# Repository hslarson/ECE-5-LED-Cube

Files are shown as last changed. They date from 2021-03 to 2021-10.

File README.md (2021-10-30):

Cube GIF (https://photos.app.goo.gl/J5VMb96Lni4Fbc2d9 "More Images")

<hr />

### Main Program:

- <b> loop </b>
  - Calls the nextLayer() member  function of the Multiplexer class on a preset interval
  - While we wait for the next layer to be drawn, the loop calls the subtasks() function to perform several smaller tasks required to draw the matrix
- <b>subtasks</b>
  - Each subtask referenced in this function is called once for every complete matrix that is sent to the cube. The function must be reset after every iteration
  - The first step (case 0) is calling the checkVolume() member function of the MSGEQ7 class, this decides whether the subtasks function draws a volume matrix or a spectrum matrix
  - Next, we collect the data required to construct the matrix. This is only required if we are drawing a spectrum matrix
  - Then, we construct the matrix itself. This is handled entirely by the respective classes
  - Lastly, we queue the matrix we just drew, meaning that it will be shown in the next iteration of the loop

### Multiplexer Class:

- <b>setMatrix</b>
  - Uses memcpy to either queue a new matrix or allow the queued matrix to be shown
- <b>nextLayer</b>
  - Handles the drawing of individual layers and the queuing of matrices
  - First, calls the constructData() function to format the data in a way that the registers will understand
  - Then, calls the sendData() function to send the data to the cube
- <b>constructData</b>
  - A helper function for nextLayer() that handles the mapping of output pins and the conversion of the resultant binary array to an integer array
- <b>sendToCube</b>
  - Uses the SPI bus to send the data from the constructData() function to the shift registers

### MSGEQ7 Class:

- <b>getSpectrum</b>
  - Reads data from the MSGEQ7 breakout board using analogRead()
- <b>normSpectrum</b>
  - Takes the array from the getSpectrum() function and converts from 7 channels to 36
- <b>makeSpectrumMatrix</b>
  - Maps each frequency band to a specific column of the cube
  - Applies a threshold to the raw reading to decide how many LED’s to light in each column and constructs a Boolean matrix based on this data
- <b>queueMatrix</b>
  - Calls the setMatrix() member of the Multiplexer class to queue the matrix that was built by the makeSpectrumMatrix() function

### VolumeControl Class:

- <b>checkVolume</b>
  - Uses a timer and the getVolume() function to decide whether or not to draw a volume matrix
- <b>getVolume</b>
  - Reads data from the volume potentiometer and normalizes the reading
  - Creates a running average of the normalized readings
- <b>makeVolumeMatrix</b>
  - Takes the current volume reading and creates a Boolean matrix that displays the volume as front-to-back bars that ascend each column then move from left to right to the next column
- <b>queueMatrix</b>
  - Takes the matrix that was constructed by the makeVolumeMatrix and queues it to be shown on the cube

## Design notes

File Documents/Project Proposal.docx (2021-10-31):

Project Title: LED Matrix Audio Visualizer

Group Members: Hunter Larson, Andy Liu, Kaitlyn Yau

1. Project Goal and Functionality

Our goal is to create an LED cube with the primary function of visualizing audio signals. This will be accomplished by sampling the audio signal from a 3.5mm jack (plugged into a phone or other audio player) a 7-band frequency analyzer and dividing the output into 16 frequency bands.

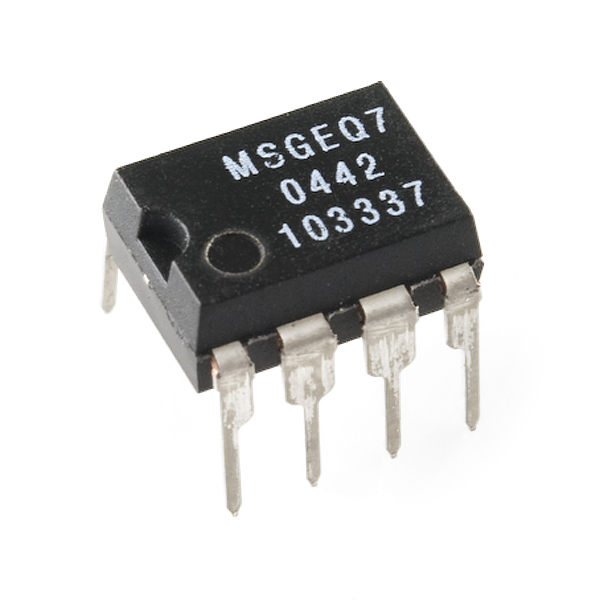
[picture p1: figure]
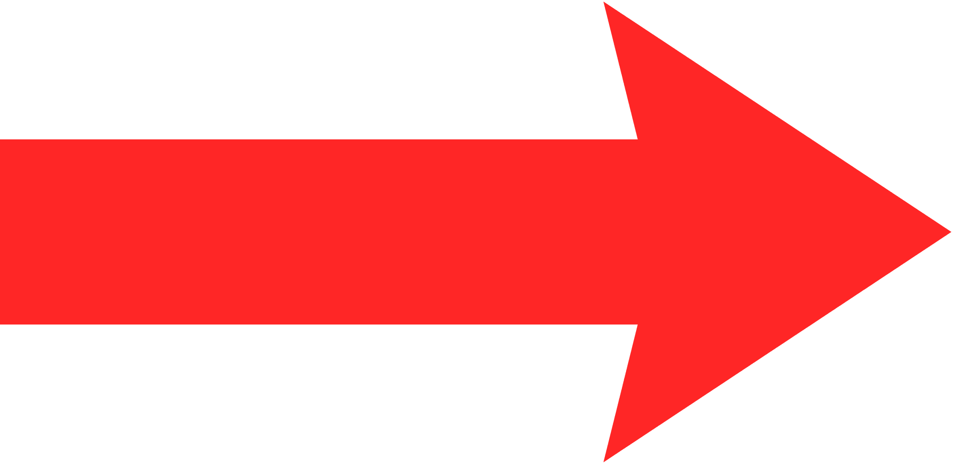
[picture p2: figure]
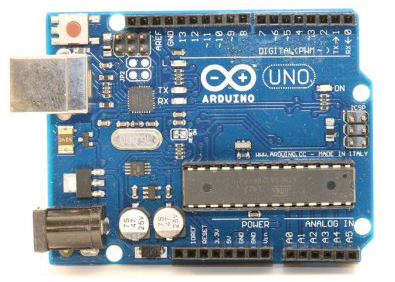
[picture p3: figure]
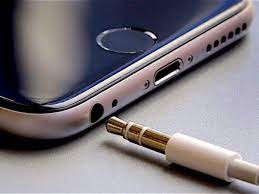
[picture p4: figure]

Figure 1: Process for decomposing audio into frequencies components (Image Credits (https://docs.google.com/document/d/1sJ7cVf4u0EIYqTToMvButSBCdlmTL1YI7-39VEIXNug/edit?usp=sharing))

Once we’ve computed the frequency bands, we will use shift registers to turn on certain columns in the matrix (each column in the cube shares a common anode) while powering only one layer at a time (each layer shares a common cathode). Repeating this process in rapid succession will allow us to create a persistence of vision effect, thus conveying the magnitude of each frequency band by varying the number of LED’s we turn on in each column.

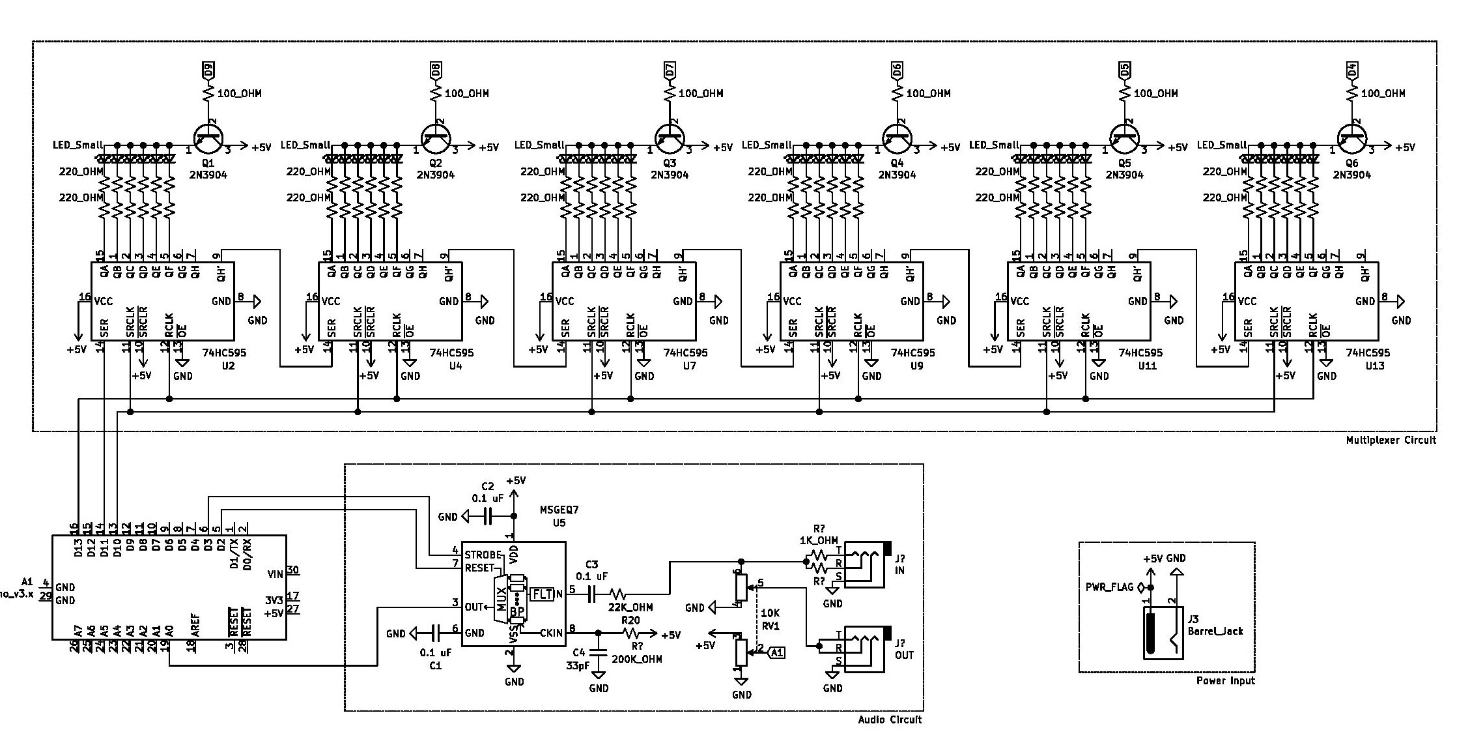
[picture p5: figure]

Figure 2: Shows the schematic for both the multiplexer and the MSGEQ7 circuit

Time permitting, we will add the ability to display other patterns on the cube when no audio source is connected.

2. Hardware Components
1. 1x Arduino Nano (Already Have)
2. 1x USB Wall Adapter & Cable w/ Barrel Jack (already have)
3. 1x (Female) Barrel Connector for Power (already have)
4. 1x Rocker Switch for Power (already have)
5. 2x 3.5mm Audio Jacks (already have)
6. 6x NPN Transistors (Already Have)
7. 1x Protoboard (https://www.amazon.com/Double-Sided-Protoboard-Prototyping-10X15CM/dp/B07HFFLGFV)
8. 1x Seven Band Spectrum Analyzer Board (https://www.amazon.com/MSGEQ7-Spectrum-Analyzer-Breakout-Stereo/dp/B08GY46BY8?s=electronics)
9. 216x D (https://www.amazon.com/100pcs-Ultra-Bright-Emitting-Diffused/dp/B01GE5NB5U)iffused, White LED’s (https://www.amazon.com/100pcs-Ultra-Bright-Emitting-Diffused/dp/B01GE5NB5U)
10. 72x 220-ohm Resistors (https://www.amazon.com/Projects-100EP512220R-220-Resistors-Pack/dp/B0185FID0K)
11. 6x Shift Registers (https://www.amazon.com/MCIGICM-74HC595-SN74HC595N-Register-registers/dp/B07HFWB9L9)
12. 6x IC Sockets (https://www.amazon.com/Uxcell-a11090300ux0244-2-54mm-Socket-Adaptors/dp/B0079SM1LW)
13. 3x Ribbon Cables (https://www.amazon.com/gp/product/B07FKRYJVR/ref=ppx_yo_dt_b_asin_title_o02_s00?ie=UTF8&psc=1)
14. 3x Connectors For Ribbon Cables (https://www.amazon.com/JZK-crimper-crimping-connectors-assorted/dp/B07PCQ5VMV)

Price Breakdown:

1. Arduino - $0
2. Power Supply - $0
3. Barrel Connector - $0
4. Rocker Switch - $0
5. 3.5mm Jacks - $0
6. Transistors - $0
7. Protoboard - $12
8. Spectrum Analyzer - $20
9. LED’s - $19
10. Resistors - $7
11. Shift Registers - $7.50
12. IC Sockets - $7
13. Ribbon Cables - $9
14. Ribbon Cable Connectors - $7

Total: $81.5

3. Design Timeline
1. Week 5: Order parts
2. Week 6: Start building LED Matrix, Start Controller Circuit
3. Week 7: Finish Controller Circuit, Start Programing
4. Week 8: Finish Programming, finish building LED matrix
5. Week 9: Debugging and/or Additional Patterns
4. Documentation
1. Github Repo (https://github.com/hslarson/ECE-5-LED-Cube)
2. MSGEQ7 Datasheet (https://www.digikey.com/htmldatasheets/production/1844111/0/0/1/msgeq7.html)
3. LED Datasheet (https://www.vishay.com/docs/85198/vlhw4100.pdf)
4. Shift Register Datasheet (https://www.ti.com/lit/ds/scls041i/scls041i.pdf?ts=1611948098373)
5. Transistor Datasheet (https://www.sparkfun.com/datasheets/Components/2N3904.pdf)

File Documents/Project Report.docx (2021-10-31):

LED Matrix Audio Visualizer

Group Members: Hunter Larson, Andy Liu, Kaitlyn Yau

# 1. Device Functionality

We created a 6x6x6 LED cube with the primary function of visualizing audio signals. This will be accomplished by sampling the audio signal from a 3.5mm jack (plugged into a phone or other audio player) with the MSGEQ7, a 7-band graphic equalizer and dividing the output into 36 frequency bands.

Once we’ve computed the frequency bands, we will use shift registers to turn on certain columns in the matrix (each column in the cube shares a common anode) while powering only one layer at a time (each layer shares a common cathode). Repeating this process in rapid succession will allow us to create a persistence of vision effect, thus conveying the magnitude of each frequency band by varying the number of LED’s we turn on in each column

# 2. Hardware Components

1. 1x Arduino Nano (already have)
2. 1x USB Wall Adapter & Cable w/ Barrel Jack (already have)
3. 1x (Female) Barrel Connector for Power (already have)
4. 1x Rocker Switch for Power (already have)
5. 2x 3.5mm Audio Jacks (already have)
6. 6x NPN Transistors (Already Have)
7. 1x Protoboard (https://www.amazon.com/Double-Sided-Protoboard-Prototyping-10X15CM/dp/B07HFFLGFV) ($12.00)
8. 1x Seven Band Spectrum Analyzer Board (https://www.amazon.com/MSGEQ7-Spectrum-Analyzer-Breakout-Stereo/dp/B08GY46BY8?s=electronics) ($20.00)
9. 216x Diffused, White LED’s (https://www.amazon.com/100pcs-Ultra-Bright-Emitting-Diffused/dp/B01GE5NB5U) ($19.00)
10. 72x 220-ohm Resistors (https://www.amazon.com/Projects-100EP512220R-220-Resistors-Pack/dp/B0185FID0K) ($7.00)
11. 6x Shift Registers (https://www.amazon.com/MCIGICM-74HC595-SN74HC595N-Register-registers/dp/B07HFWB9L9) ($7.50)
12. 6x IC Sockets (https://www.amazon.com/Uxcell-a11090300ux0244-2-54mm-Socket-Adaptors/dp/B0079SM1LW) ($8.00)
13. 3x Ribbon Cables (https://www.amazon.com/gp/product/B07FKRYJVR/ref=ppx_yo_dt_b_asin_title_o02_s00?ie=UTF8&psc=1) ($9.00)
14. 3x Connectors For Ribbon Cables (https://www.amazon.com/JZK-crimper-crimping-connectors-assorted/dp/B07PCQ5VMV)($7.00)

Total: $89.50

# 3. Design Timeline

Week 5: Found and ordered the parts needed for our project

Week 6: Began building the cube, managed to solder our 6 layers of LED’s.

Week 7: Came up with potential solutions to attaching our 6 layers of LED’s together (which we were having trouble with at the end of week 6). Began programming.

Week 8: Successfully attached the 6 layers of LED’s together to finish making our cube. Continued programming.

Week 9: Finished programming. Began and finished multiplexer circuit. Began audio circuit

Week 10: Finished audio circuit, attached cube to circuit. Currently debugging.

# 4. Software Design

https://github.com/hslarson/ECE-5-LED-Cube The README in the github link contains the details of every function we used including the ones in the flowchart below. There, you can also find our completed code.

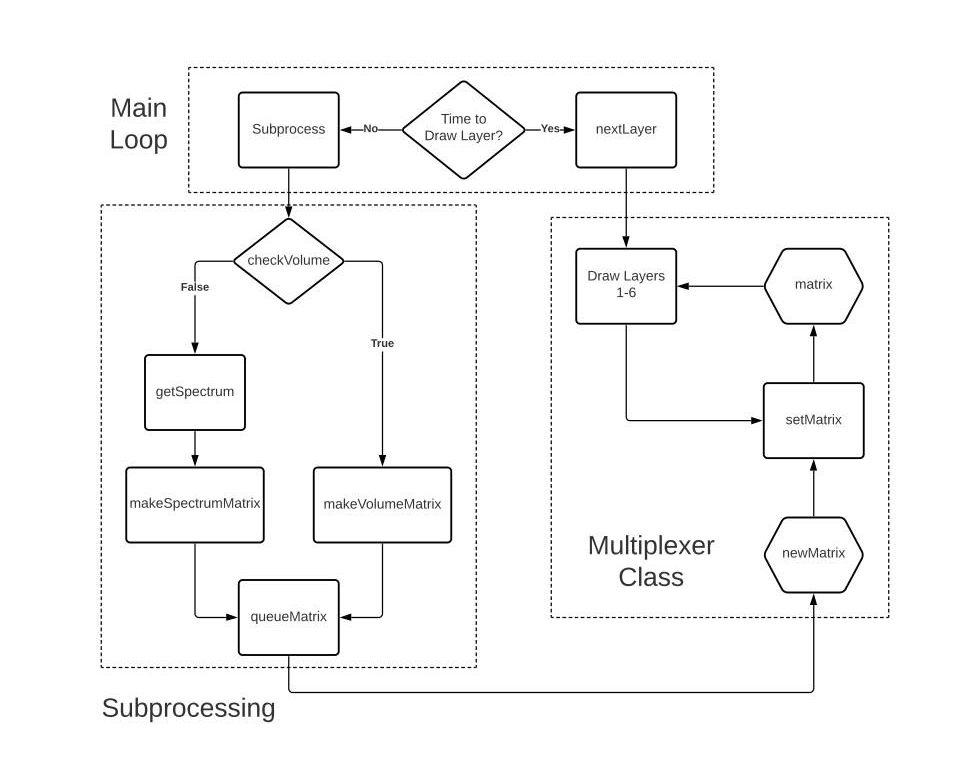
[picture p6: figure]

# 5. Circuit Schematic

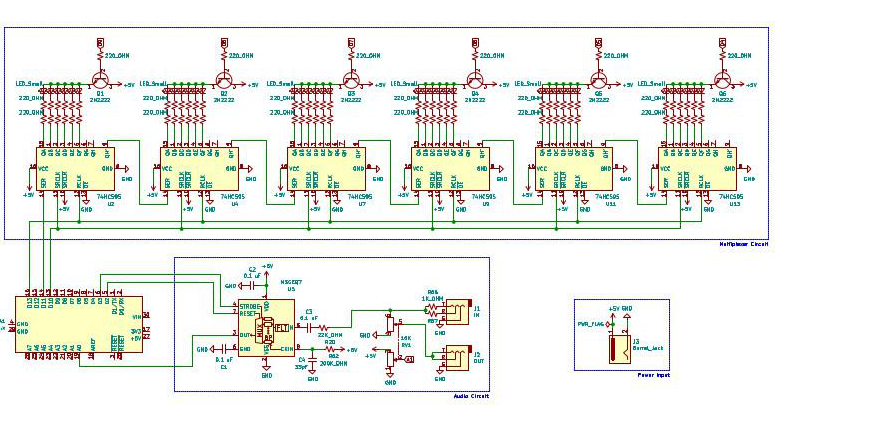
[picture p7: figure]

# 6. Circuit Prototype

Cube and Circuit Exterior :

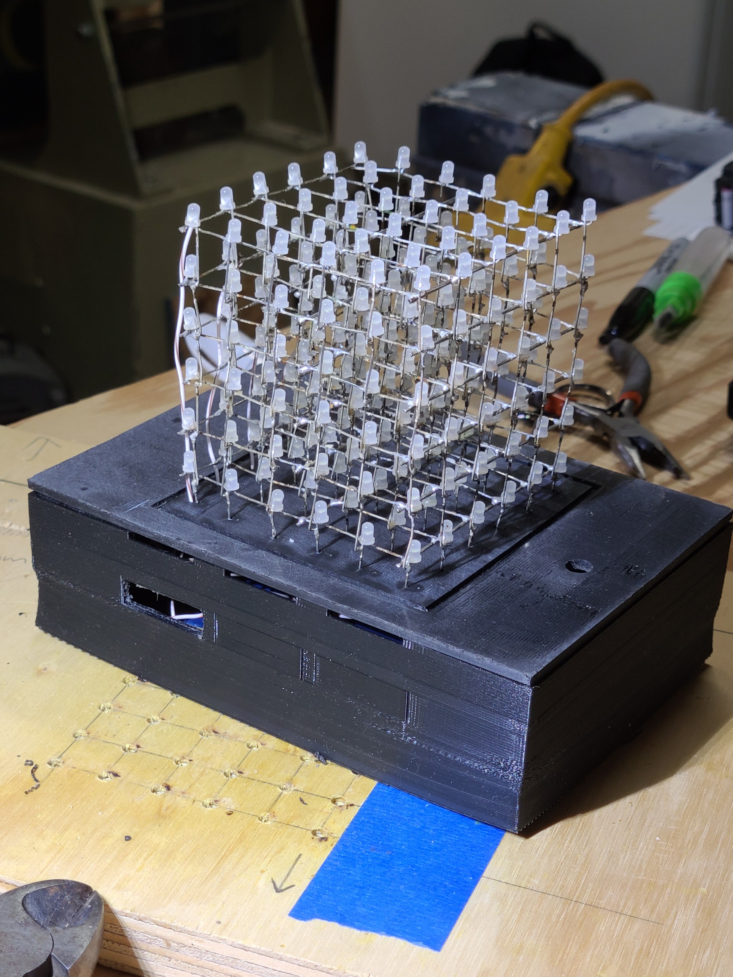
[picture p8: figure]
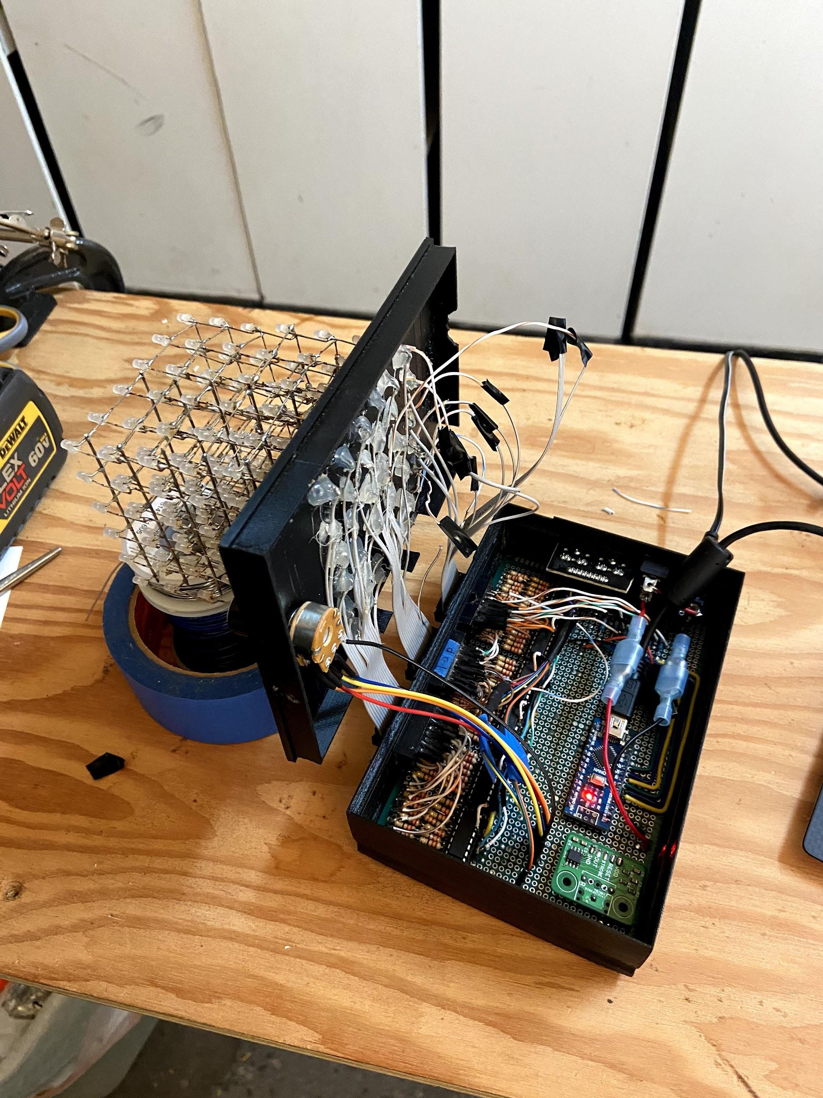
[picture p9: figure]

Circuit Top and Bottom View :

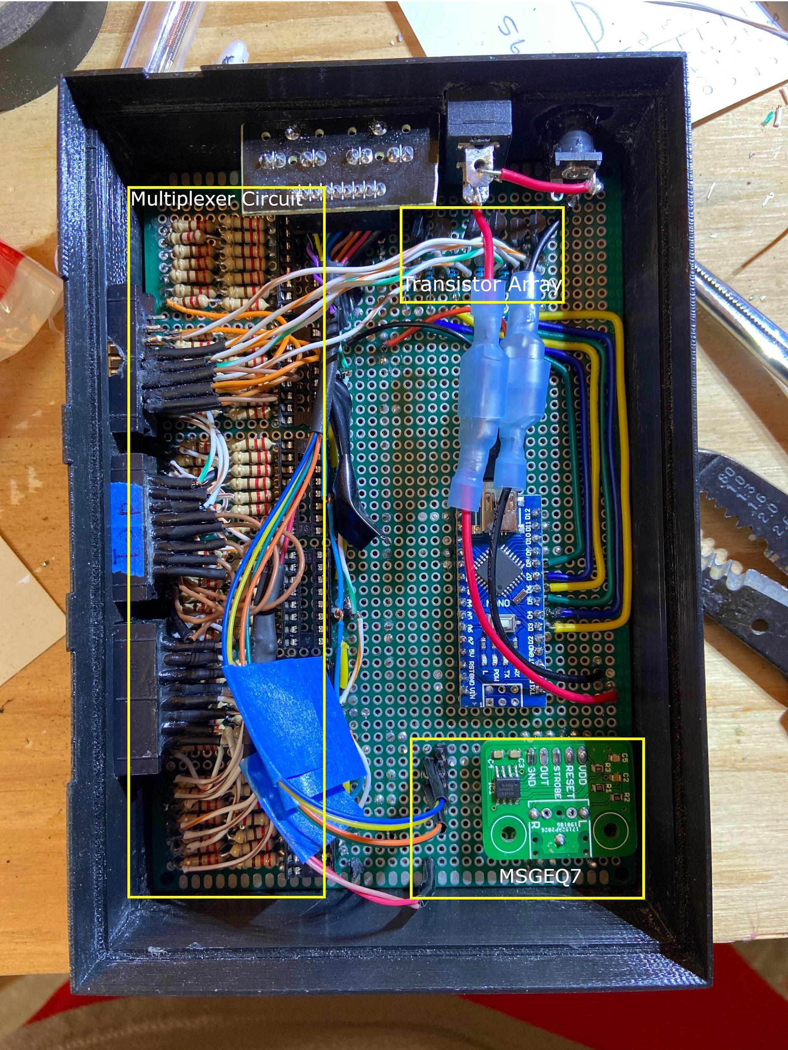
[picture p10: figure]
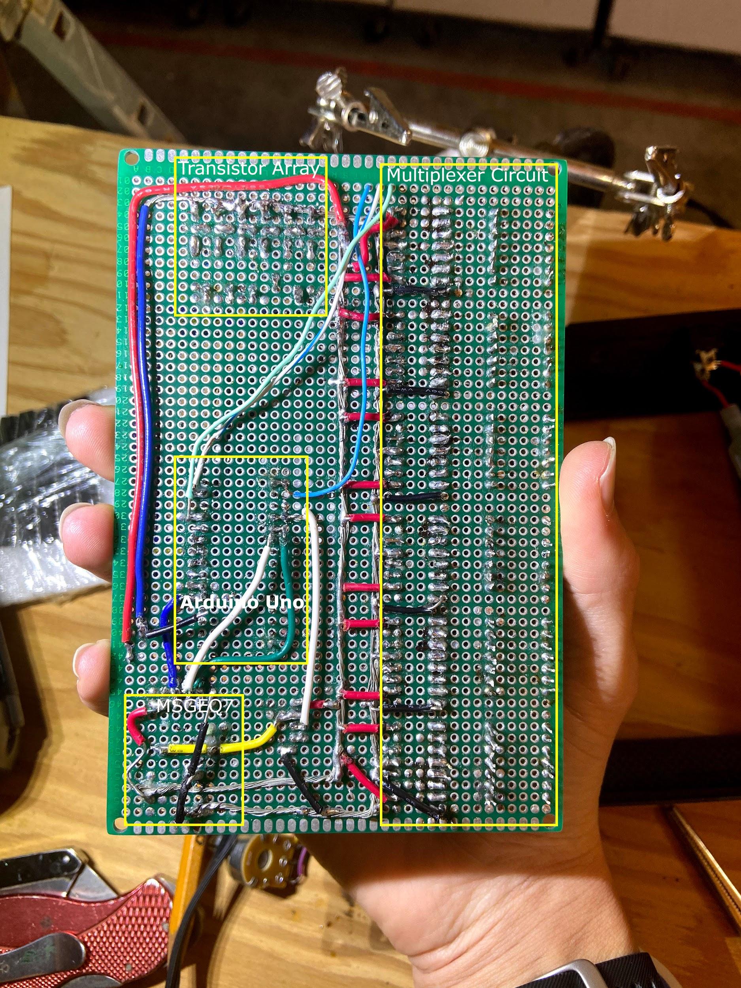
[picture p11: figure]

# 7. Testing

- Tried to build a MSGEQ7 circuit using loose components, didn’t work
  - Used oscilloscope to determine that both MSGEQ7 chips I had received were defective
- Attempted to find which shift register pins corresponded to which led’s
  - Found that around 4 led’s were disconnected
  - Found that some of the pins of the connectors were loose and therefore not connecting properly
- Fixed the connection issue with superglue, retested bad led’s, 2 remained unpowered
  - Connected some of the unused wires of the ribbon cable to problem led’s
  - Also fixed an issue where one of the cables had snapped
- Noticed the issue with the shift registers not getting data
  - Probed the clock/latch lines and found there was a short, still didn’t work
  - Probed the data line and found no problems
  - Probed clock line and found that nothing was happening
  - Probed the microchip of the Arduino and found that the clock signal was being generated properly
  - Determined the issue to be a broken copper trace running to pin 13 of the Arduino. Modified software to use shiftOut instead of SPI bus
- Had an issue where MSGEQ7 was unable to read data
  - Fixed this issue by plugging headphones into the output jack
  - Not sure why this fixed it, but it seems like the jacks aren’t being grounded correctly
- Had an issue where layer 4 seemed to be off when it shouldn’t be
  - Reordered the pin constants in software so that the pin that had been connected to layer 4 was connected to layer 6 and vice versa
- Found that the box lid wouldn’t close due to stiff ribbon cables
  - Tried to print a spacer, but accidentally made it too tall
  - Didn’t have time to fix it before shooting the video, so I just held the top so it was somewhat level with the base. I will probably reprint the entire base on my own time

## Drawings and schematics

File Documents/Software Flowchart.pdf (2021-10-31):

# Main Loop

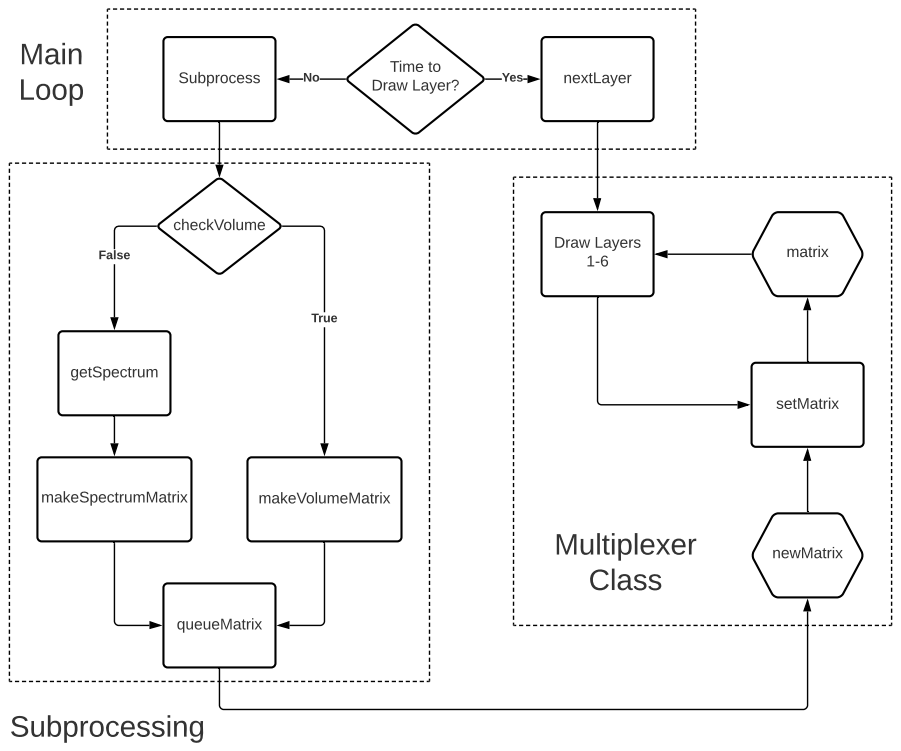
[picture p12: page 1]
Subprocess; nextLayer; Time to; Draw Layer? No; Yes; checkVolume; getSpectrum; makeSpectrumMatrix; queueMatrix; makeVolumeMatrix; False; True; Draw Layers; matrix; setMatrix; newMatrix; Subprocessing; Multiplexer Class

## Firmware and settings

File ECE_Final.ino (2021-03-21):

#include <math.h>

#include "constants.h"
#include "multiplexer.h"
#include "msgeq7.h"
#include "volume.h"

// Create Class Objects
Multiplexer   cube;
MSGEQ7        analyzer;
VolumeControl knob;

// Declare Timing Variable
unsigned long int StartTime = micros();

// Declare a function to handle subtasks
void subtasks(bool);


void setup() {
    // **Open the Serial Port**
    if (DEBUG) Serial.begin(9600);

    // **Set PinModes**
    // Transistor Pins
    for (int layer = 0; layer < 6; layer++) {
        pinMode(LAYER_PINS[layer], OUTPUT);
    }

    // Shift Register Pins
    pinMode(ShiftLatchPin, OUTPUT);
    pinMode(ShiftDataPin,  OUTPUT);
    pinMode(ShiftClockPin, OUTPUT);

    // MSGEQ7 Pins
    pinMode(AnalyzerReset, OUTPUT);
    pinMode(AnalyzerStrobe,OUTPUT);
    pinMode(AnalyzerData,  INPUT);

    // **Initialize Volume Class**
    knob.checkVolume(1);
}


void loop() {
    // Reset State Variables
    bool finished_drawing_cube = 0,
         finished_subtask = 0;

    // Reset the subtask handler
    subtasks(true);

    while (!finished_drawing_cube) {
        // Do one subtask before drawing each layer
        if (!finished_subtask) {
            subtasks(false);
            finished_subtask = true;
        }

        // Attempt to show the layers on a preset interval
        else if (abs(micros() - StartTime) / (int)LAYER_SHOW_TIME) {
            StartTime = micros();
            finished_subtask = false;

            if (cube.nextLayer())
                finished_drawing_cube = true;
        }
    }
}


void subtasks (bool reset) {
    static int task = 0;
    static bool mode = MODE_SPECTRUM;

    if (reset) {
        task = 0;
        return;
    }

    switch (task) {

    // Check the state of the volume know
    case 0:
        // Switch into volume mode if there have been changes in the volume knob
        if (knob.checkVolume())
            mode = MODE_VOLUME;
        else
            mode = MODE_SPECTRUM;

        if (DEBUG) {
            Serial.print("Draw Mode: ");
            Serial.print((mode ? "Spectrum\n" : "Volume\n"));
        }
        break;

    // Collect data (if necessary)
    case 1:
        // Read data from the MSGEQ7 circuit
        if (mode == MODE_SPECTRUM)
            analyzer.getSpectrum();

        break;

    // Construct the matrix
    case 2:
        if (mode == MODE_SPECTRUM)
            analyzer.makeSpectrumMatrix();
        else
            knob.makeVolumeMatrix();
        break;

    // Queue the matrix to be shown
    case 3:
        if (mode == MODE_SPECTRUM)
            analyzer.queueMatrix(cube);
        else
            knob.queueMatrix(cube);
        break;
    };

    task++;
    return;
}

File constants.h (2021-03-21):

#ifndef constants
#define constants


// ** Enable Debug Mode **
#define DEBUG false

/*** PIN CONSTANTS ***/
// Transistor Pins
#define Layer1 8
#define Layer2 7
#define Layer3 6
#define Layer4 3
#define Layer5 5
#define Layer6 4

// Shift Register Pins
#define ShiftClockPin 12
#define ShiftDataPin  11
#define ShiftLatchPin 9

// MSGEQ7 Pins
#define AnalyzerData   A1
#define AnalyzerReset  2
#define AnalyzerStrobe A2

// Volume Knob Pin
#define VolumePin A0


/*** DISPLAY CONSTANTS ***/
/*
  How to set PIN_CONFIGURATION

  Shift Register 1:    Shift Register 2:    Shift Register 3:
  Q0: 1                Q0: 9                Q0: 17             
  Q1: 2                Q1: 10               Q1: 18             
  Q2: 3                Q2: 11               Q2: 19             
  Q3: 4                Q3: 12               Q3: 20             
  Q4: 5                Q4: 13               Q4: 21             
  Q5: 6                Q5: 14               Q5: 22             
  Q6: 7                Q6: 15               Q6: 23             
  Q7: 8                Q7: 16               Q7: 24             

  Shift Register 4:    Shift Register 5:    Shift Register 6:
  Q0: 25               Q0: 33               Q0: 41             
  Q1: 26               Q1: 34               Q1: 42             
  Q2: 27               Q2: 35               Q2: 43             
  Q3: 28               Q3: 36               Q3: 44             
  Q4: 29               Q4: 37               Q4: 45             
  Q5: 30               Q5: 38               Q5: 46             
  Q6: 31               Q6: 39               Q6: 47             
  Q7: 32               Q7: 40               Q7: 48             

  Using the values above, assign integer values to the 2d matrix below
  to denote which output pin of the shift registers each column is connected to

  Note:
    The front of the cube is towards the top of the page
    You are looking at the cube from the top down
*/
const short PIN_CONFIGURATION[][6] = {
  //          ^
  //        Front
  {48, 40, 39, 47, 46, 38},
  {37, 44, 36, 43, 34, 45},
  {30, 24, 42, 35, 31, 32},
  {29, 23,  5, 22, 27, 21},
  {26, 19, 14, 16, 15, 20},
  {18, 13, 10, 12,  8, 11}
};


// Organizes the layer pins so they can be iterated through more easily
const int LAYER_PINS[] = {Layer1, Layer2, Layer3, Layer4, Layer5, Layer6};

// Display modes
#define MODE_SPECTRUM true
#define MODE_VOLUME false

// The number of times to refresh the cube per second
#define FRAME_RATE 60

// The number of microseconds each layer is shown
#define LAYER_SHOW_TIME ((double)1000000/FRAME_RATE/6)


/*** AUDIO analyzer CONSTANTS ***/
/*
  How to set FREQ_PLACEMENT

  [1, 36] : References a location in the normalized frequency array
  [0]     : References the average of all of the raw frequency readings
  [-1, -7]: References a location in the raw frequency array

  Fill out the grid similarly to the pin_configuration array (see instructions above)
  You'll also find several examples below
*/

/*
// Normal
const short FREQ_PLACEMENT[][6] = {
  //          ^
  //        Front
  {1,  2,  3,  4,  5,  6 },
  {7,  8,  9,  10, 11, 12},
  {13, 14, 15, 16, 17, 18},
  {19, 20, 21, 22, 23, 24},
  {25, 26, 27, 28, 29, 30},
  {31, 32, 33, 34, 35, 36}
};
*/


// 90-Degree Rotated
const short FREQ_PLACEMENT[][6] = {
  //          ^
  //        Front
  {31, 25, 19, 13, 7,  1},
  {32, 26, 20, 14, 8,  2},
  {33, 27, 21, 15, 9,  3},
  {34, 28, 22, 16, 10, 4},
  {35, 29, 23, 17, 11, 5},
  {36, 30, 24, 18, 12, 6}
};


/*
// Sprial
const short FREQ_PLACEMENT[][6] = {
  //          ^
  //        Front
  {1,  2,  3,  4,  5,  6 },
  {20, 21, 22, 23, 24, 7 },
  {19, 32, 33, 34, 25, 8 },
  {18, 31, 36, 35, 26, 9 },
  {17, 30, 29, 28, 27, 10},
  {16, 15, 14, 13, 12, 11}
};
*/

/*
// Blocks
const short FREQ_PLACEMENT[][6] = {
  //          ^
  //        Front
  {-1,-1,  -2,-2,  -3,-3},
  {-1,-1,  -2,-2,  -3,-3},
  {-1,-1,  -2,-2,  -3,-3},
  
  {-5,-5,  -6,-6,  -7,-7},
  {-5,-5,  -6,-6,  -7,-7},
  {-5,-5,  -6,-6,  -7,-7}
};
*/

// Use this to set the index of each of the raw frequency readings in the normed array
// More Space = Greater "Resolution";
const short PRIMARY_FREQ_LOCATIONS[] = {0, 6, 12, 18, 24, 30, 35};
const short PRIMARY_FREQ_LOCATIONS_ASCENDING[] = {0, 6, 12, 18, 24, 30, 35}; // A sorted version of the previous array to make interpolation faster

// This array sets the MINIMUM magnitude (0 - 1023) to light a particular layer of led's
// const short FREQ_THRESHOLDS[] = {0 , 29, 78, 94, 130, 276};
const short FREQ_THRESHOLDS[] = {146, 292, 438, 584, 730, 876};

// How many points to consider in the rolling average
#define FREQ_AVERAGING_POINTS 4


/*** VOLUME CONSTANTS ***/
// The amount by which the raw volume reading needs to change in order to display the volume (on a scale from 1 - 36)
#define VOLUME_CHANGE_THRESHOLD 2

// How many points to consider in the rolling average
#define VOLUME_AVERAGING_POINTS 4
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

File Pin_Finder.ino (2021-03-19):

// This program is designed to help you set the PIN_CONFIGURATION array in constants.h
// For each number in the sequence, record the location of the LED that lights up (if any) and add it
// to the array. To move to the next number, just send something to the Arduino via the serial monitor


#define clk 12
#define dat 11
#define lat 9
#define lyr 8

int c = 0;

void setup() {
  Serial.begin(9600);

  pinMode(clk, OUTPUT);
  pinMode(dat, OUTPUT);
  pinMode(lat, OUTPUT);
  pinMode(lyr, OUTPUT);

  digitalWrite(lyr, HIGH);

  for (int r = 0; r < 6; r++) {
    digitalWrite(lat, LOW);
    shiftOut(dat, clk, LSBFIRST, 0); 
    digitalWrite(lat, HIGH);
  }
}

void loop() {
  Serial.println(c + 1);

  digitalWrite(lat, LOW);
  
  digitalWrite(dat, (c++ == 0 ? HIGH : LOW));
  digitalWrite(clk, HIGH);
  delay(1);
  digitalWrite(clk, LOW);
  
  digitalWrite(lat, HIGH);
  
  if (c > 47)
    c = 0;

  // Wait for serial input
  while (!Serial.available()) { delay(10); }
  while(Serial.available()) { Serial.read(); }
}

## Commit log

2021-02-22 Added function definitions, fixed constants
    [ECE_Final.ino, constants.h]
2021-03-19 Fixed pin assignments
2021-10-31 Pulled project files off gdrive. Not sure if they're current
    [ECE5.kicad_pcb, ECE5.sch]
